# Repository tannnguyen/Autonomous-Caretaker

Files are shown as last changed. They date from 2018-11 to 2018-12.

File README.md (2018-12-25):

# Autonomous Caretaker

Autonomous Caretaker is the final project for class 530.420 Mechatronics in Spring 2017 at Johns Hopkins University. As a team of engineers, we built a futuristic robot that can recognize and put off fire and then rescue another robot on its way back to base. We want to share our results (including Arduino codes, 3D design, and circuit).

## Mission
Given a hypothetical situation in the future where everyone has a supporting robot with them. An elderly human is sleeping on the beach and forgets to put off the campfire. The robot needs to recognize the fire, alert the elders to wake up, collect the water, put off the fire, and then bring some water back to the elderly. 

## Approach
For our robot, we plan to build a 2-story robot where it can store water in a syringe system at the bottom and all the control system is on top. We use 2 Arduinos, each controls a story within the robot. To support this robot, we use a 4-wheel robot for stability, Pixy for color and object recognition, various types of motors to control different moving components in the robot.

Our steps to solve the problems:

    Milestone 1: 
    Step 1: Looking for the fire (registered by the color red)
    Step 2: Once found, looking for the elderly
    Step 3: Move towards the elderly
    Step 4: Once reach the elderly, turn on the siren
    Step 4.5 (for elderly): Elderly hears the siren and move to safety

    Milestone 2:
    Step 5: Move backward and look for the water (registered by the color blue)
    Step 6: Identify where the water is
    Step 7: Move to the water.
    Step 8: Pick up the water (send signal to bottom Arduino)
    Step 9: Move back a bit, look for the fire
    Step 10: Go to the fire.
    Step 11: Distribute the water (send the signal to the bottom Arduino)
    Step 12: Go to the elderly.
    Step 13: Distribute the water to the elderly.
  
## Code, Design, and Circuit
Please refer to Code/ and Parts/ folders to see and download our codes and design. Refer to [Parts.md](https://github.com/tannnguyen/Autonomous-Caretaker/blob/master/Parts.md) for our parts

This is our mechanical design:
<p>
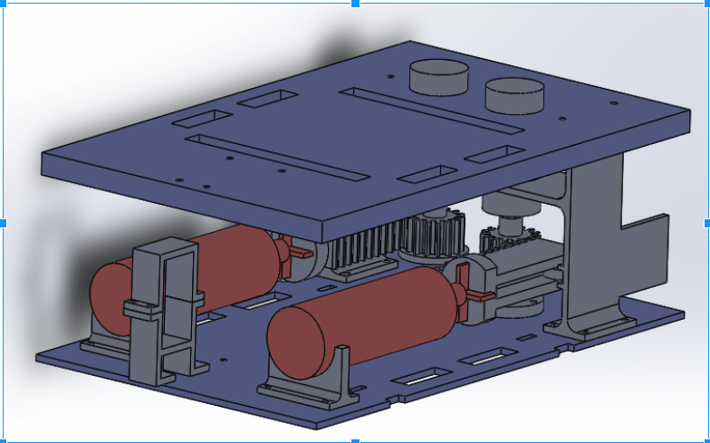
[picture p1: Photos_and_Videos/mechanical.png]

</p>

This is our circuit:
<p>
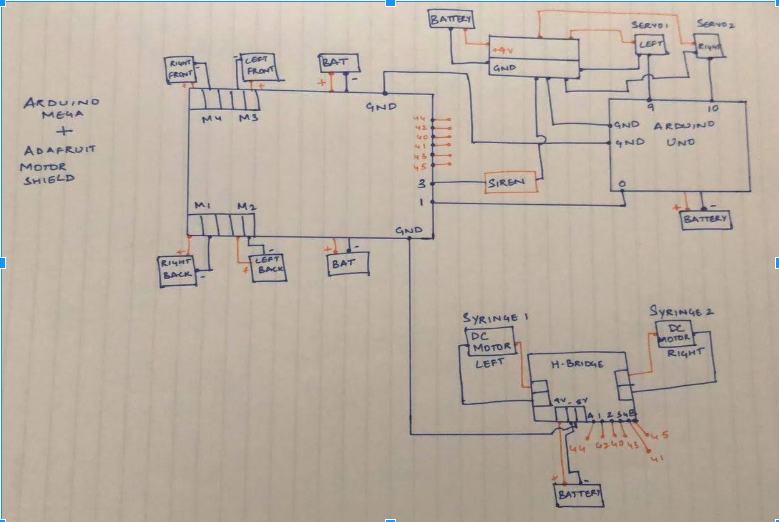
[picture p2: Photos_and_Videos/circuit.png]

</p>
This is our final robot:
<p>


 
</p>

## Demo
* Challenge 1: Please refer to this [video1](https://github.com/tannnguyen/Autonomous-Caretaker/blob/master/Photos_and_Videos/challenge1_robot.mp4) [video2](https://github.com/tannnguyen/Autonomous-Caretaker/blob/master/Photos_and_Videos/elderly.mp4)
* Challenge 2:Please refer to this [video](https://github.com/tannnguyen/Autonomous-Caretaker/blob/master/Photos_and_Videos/challenge2.mp4)
* We did not have a chance to take video of our final demo with complete steps...

## Technology
* Ardunio and its libraries
* SolidWorks (for 3D printed and lasercut part)
* Mechanical and electrical components needed to build the robot

## Authors
* Tan Nguyen
* Darshini Balamurugan
* Mona Gao

## Acknowledgement
* A lot of help and support from Morris Kraicer, Ethan Tang, Joseph Pan, and Paola Donis
* A lot of guidance from Professor Charbel Rizk

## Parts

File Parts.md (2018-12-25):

# Material List

This is all the parts we used for both the main robot and the elderly

* 1x Arduino Mega and 2x Arduino Uno
* 1x Siren
* 2x 9V DC Motors with Encoders
* 2x Positional servo motors
* 2x Chassis (Acrylic laser cut)
* 1x Pixy
* 1x Ping sensor
* Multiple 3D printed parts for support and connectors
* 8x gearbox motors and wheels (for both elderly and caretaker)
* 1x Sound Detector
* 2x Adafruit Motor shield
* 1x H-bridge
* 2x Syringes and tubes
* 1x Colored paper
* Multiple breadboards

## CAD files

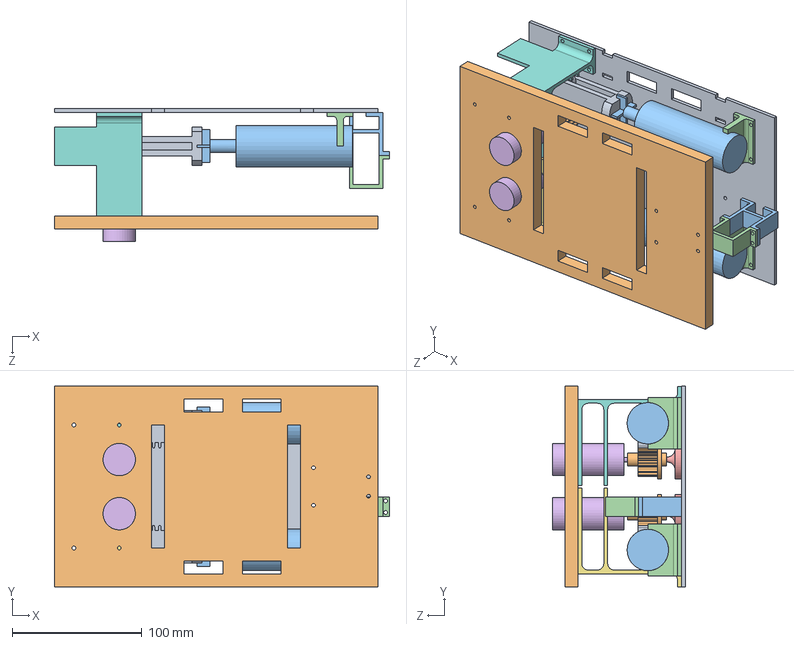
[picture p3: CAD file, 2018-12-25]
Design/syringe_system_two.SLDASM
258.7 x 155.0 x 102.5 mm
Part3rack x 2
Part1pinion125 x 2
syringe_model x 2
syringe_holder x 2
gear_stand x 2
motor_model x 2
motor_roller_wheel_holder_wall
holder_wall_mirror
chassis_4_25 (1)
top_chassis_04_26
servo_motor_support_04_27
servo_motor_upper_support

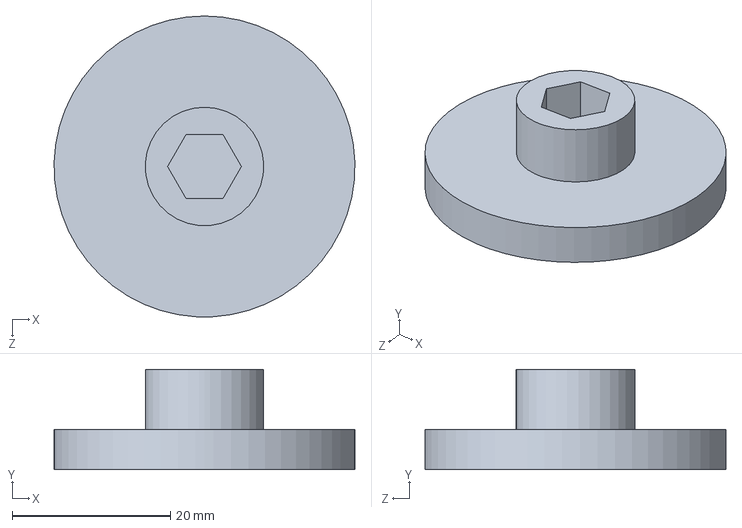
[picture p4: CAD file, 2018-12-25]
Design/syringe_end_holder.SLDPRT
38.1 x 12.7 x 38.1 mm

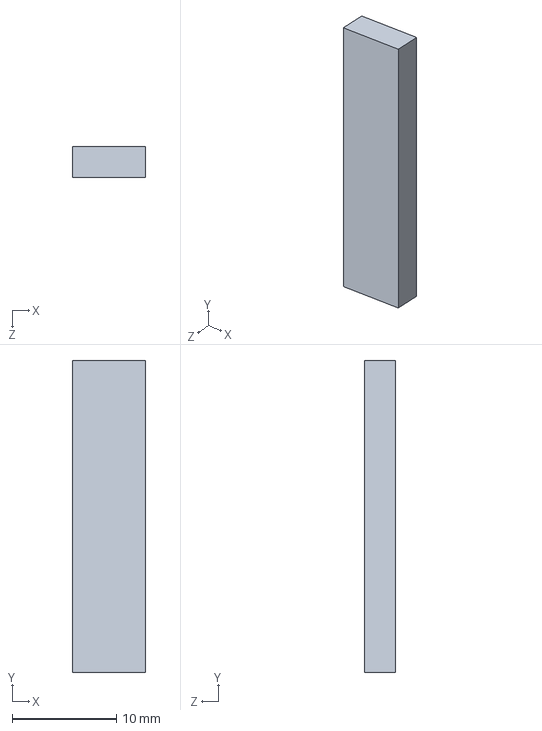
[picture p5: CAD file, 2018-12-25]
Design/slider_piece_end_stopper.SLDPRT
7.00 x 30.0 x 3.00 mm

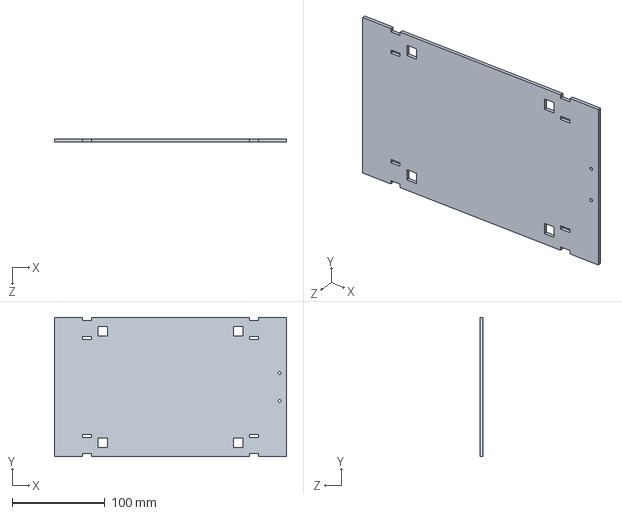
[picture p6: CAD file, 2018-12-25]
Design/robot.SLDPRT
250.0 x 150.0 x 3.00 mm

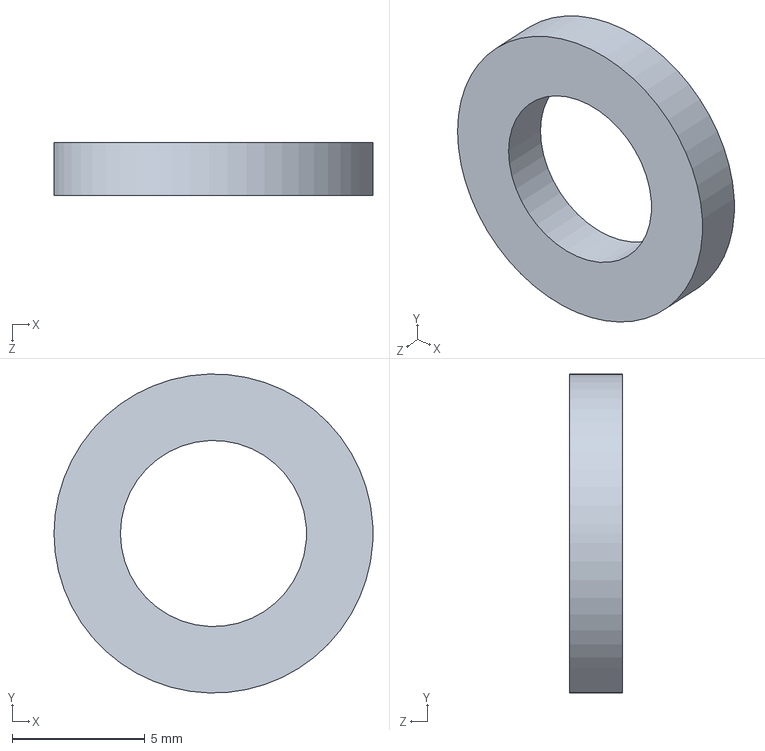
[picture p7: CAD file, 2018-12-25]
Design/bearing_holder_horizontal.SLDPRT
12.0 x 12.0 x 2.00 mm

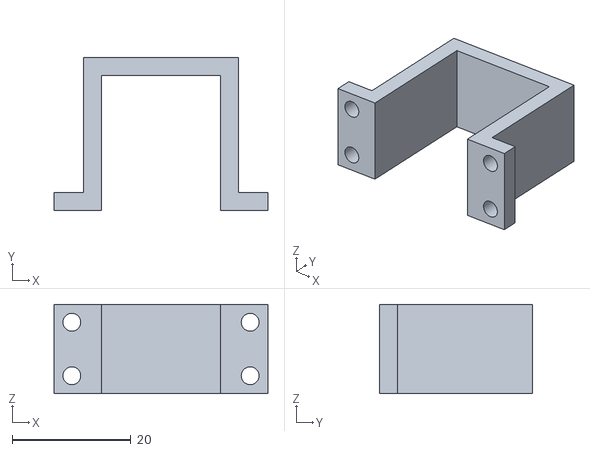
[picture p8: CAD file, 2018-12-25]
Design/servo_motor_upper_support_04_28.STL
36.0 x 25.7 x 15.0

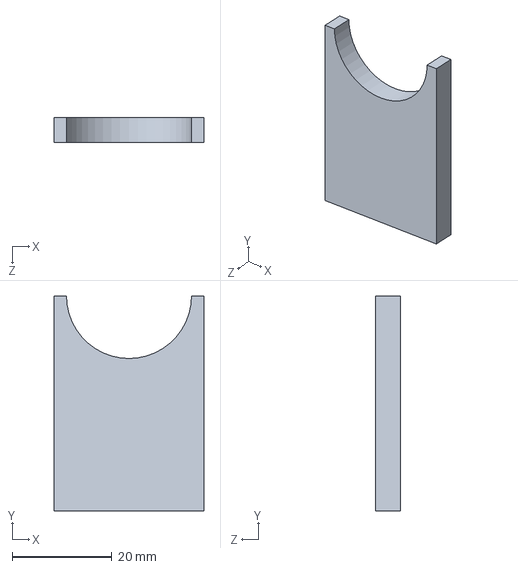
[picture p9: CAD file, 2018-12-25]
Design/motor_positioner.SLDPRT
30.0 x 43.0 x 5.00 mm

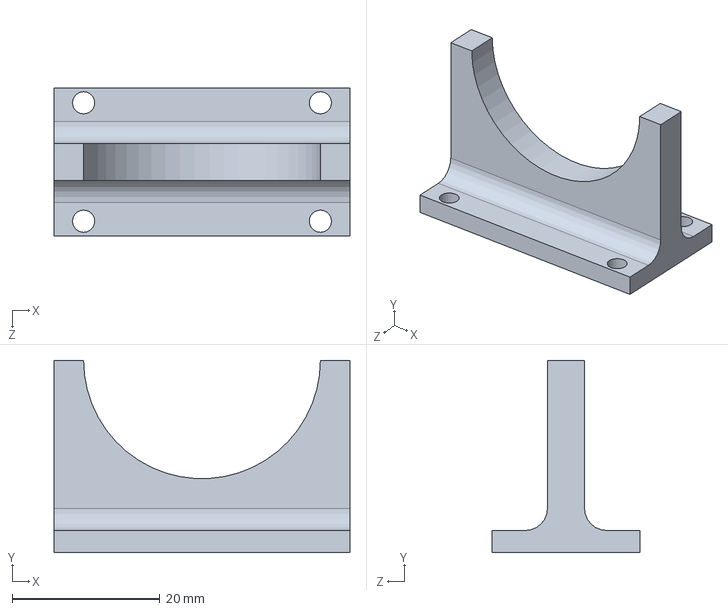
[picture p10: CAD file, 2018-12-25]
Design/syringe_holder.SLDPRT
40.0 x 26.0 x 20.0 mm

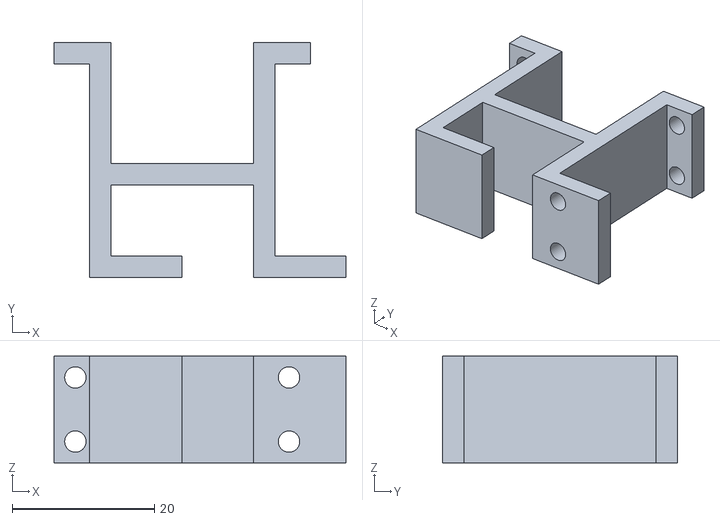
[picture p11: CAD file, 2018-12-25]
Design/servo_motor_support_04_28.STL
41.0 x 33.0 x 15.0

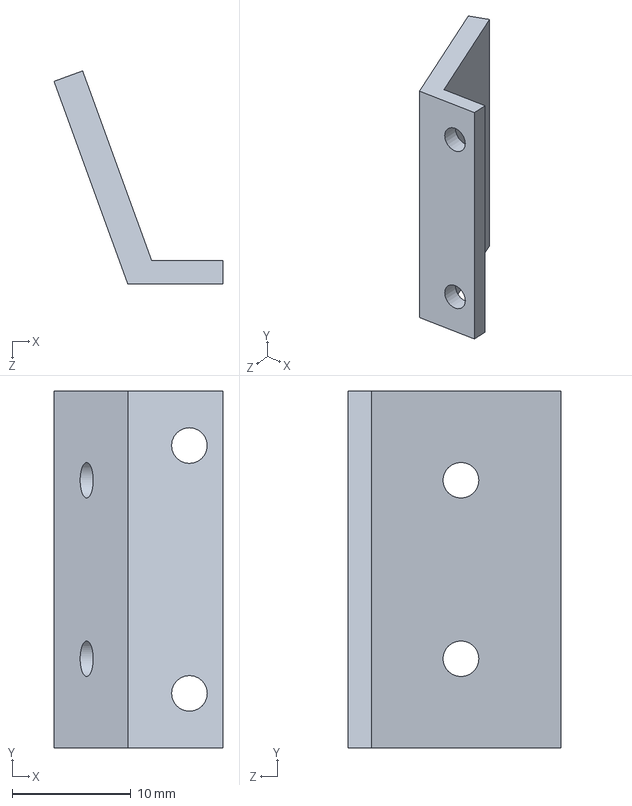
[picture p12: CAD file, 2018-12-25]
Design/pixy_slanted.SLDPRT
14.2 x 30.0 x 17.9 mm

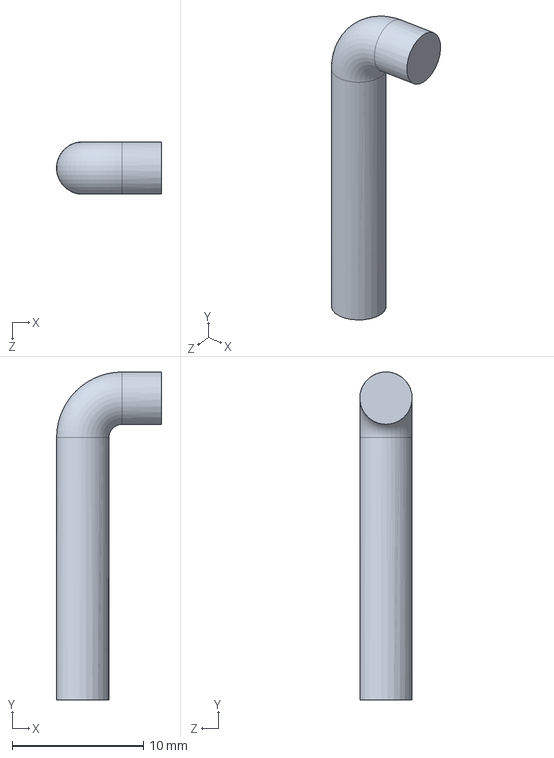
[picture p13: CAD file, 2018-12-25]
Design/arm_between_gear_roller.SLDPRT
8.00 x 25.0 x 4.00 mm

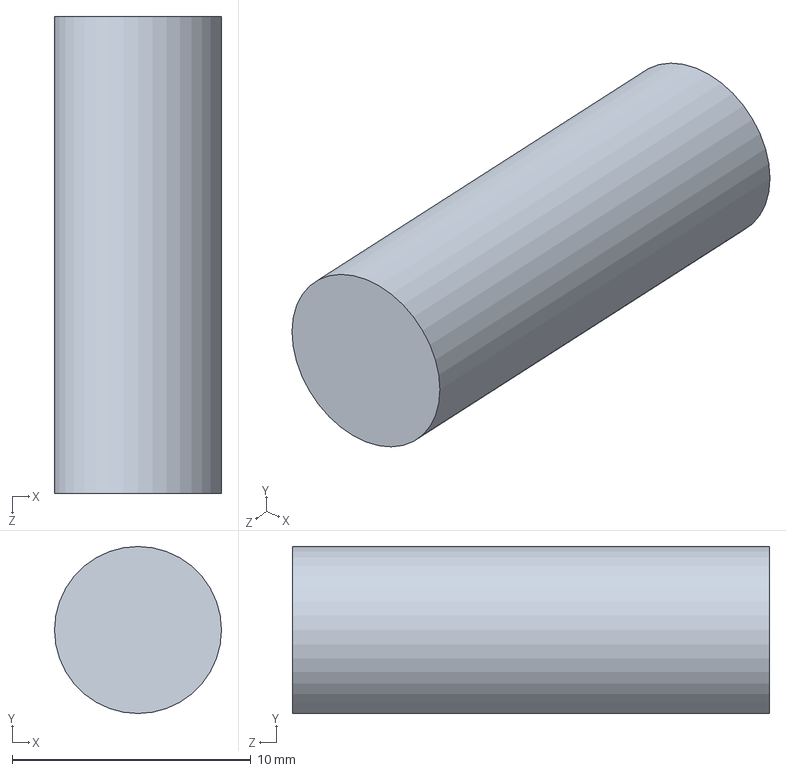
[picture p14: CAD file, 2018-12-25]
Design/shaft_to_gear.SLDPRT
7.00 x 7.00 x 20.0 mm

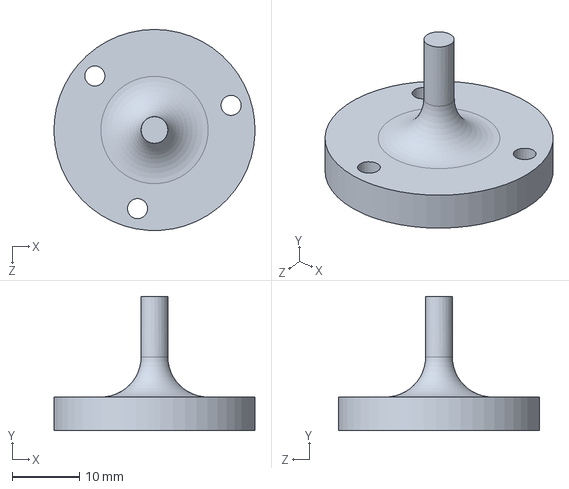
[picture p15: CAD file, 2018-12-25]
Design/gear_stand.SLDPRT
30.0 x 20.0 x 30.0 mm

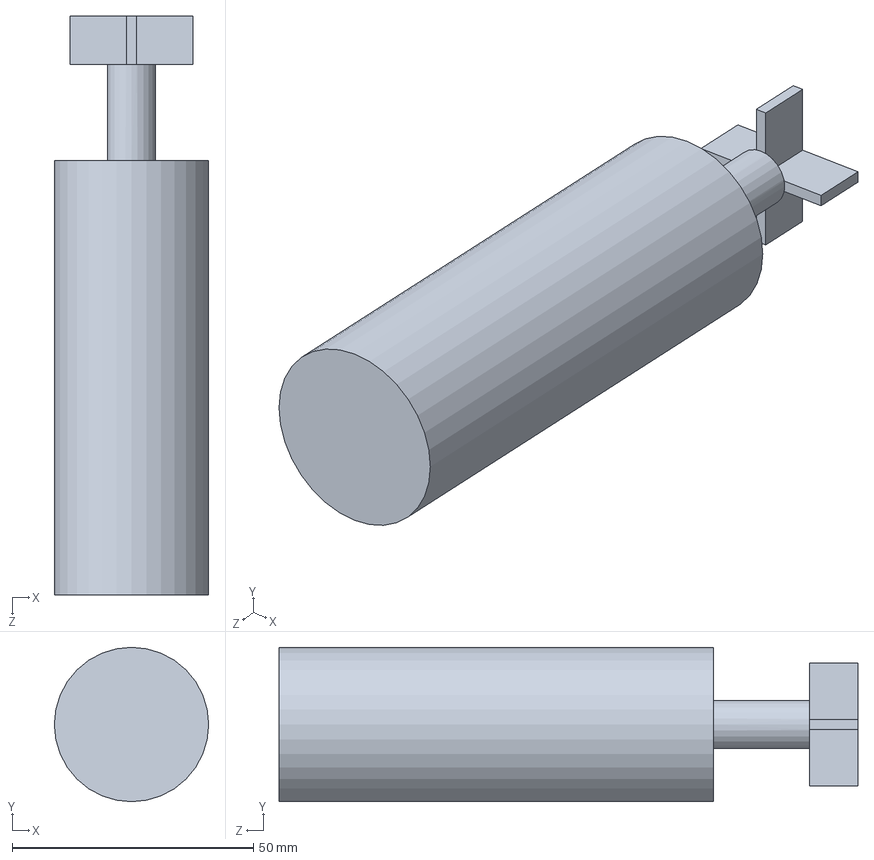
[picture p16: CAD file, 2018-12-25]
Design/syringe_model.SLDPRT
32.0 x 32.0 x 120.0 mm

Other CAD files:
Design/T for wheels2.SLDPRT
Design/syringe_holder_mirror.STL
Design/part3rack_mirror.STL
Design/holder_wall_mirror.STL
Design/Part1pinion125_04_28.STL
Design/elderly_laser_cut_04_06_18.SLDPRT
Design/motor_model.SLDPRT
Design/motor_roller_wheel_holder_wall.SLDPRT
Design/top_chassis_04_26.SLDPRT

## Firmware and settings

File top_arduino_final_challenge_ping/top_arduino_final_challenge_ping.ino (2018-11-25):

#include <Wire.h>
#include <Adafruit_MotorShield.h>
#include "utility/Adafruit_MS_PWMServoDriver.h"

// Include headers for SPI port and pixy camera
#include <SPI.h>
#include <Pixy.h>

// Define all speeds and delay here
#define water 3000
#define hose 500
#define rotateSpeed 200

// Define all ports here
#define siren 3
#define signalPin 2
#define ping 7
#define enA 45
#define enB 44
#define in1 43
#define in2 41
#define in3 42
#define in4 40
/*
   Decode for motors:
   Left syringe is 45 43 41 with 41 HIGH means Pull
   Right syringe is 44 42 40 with 42 HIGH means Pull
*/

// Create the motor shield object with the default I2C address
Adafruit_MotorShield AFMS = Adafruit_MotorShield();

// Select which 'port' M1, M2, M3 or M4. In this case, M1
Adafruit_DCMotor *leftFrontMotor = AFMS.getMotor(3);
// You can also make another motor on port M2
Adafruit_DCMotor *rightFrontMotor = AFMS.getMotor(2);
Adafruit_DCMotor *rightBackMotor = AFMS.getMotor(1);
Adafruit_DCMotor *leftBackMotor = AFMS.getMotor(4);

Pixy pixy;

//put all the variables here!
int color_fire = -1;
int color_elderly = -1;
int color_water = -1;

uint16_t blocks;
int x = -1;
int area = -1;
int height = -1;
// stores horizontal distance of object in Pixy camera

void setup() {
  // put your setup code here, to run once:
  AFMS.begin(); // create with default frequency 1.6KHz or pass hz value in function
  pixy.init();
  Serial.begin(9600);
  pinMode(siren, OUTPUT);
  pinMode(enA, OUTPUT);
  pinMode(enB, OUTPUT);
  pinMode(in1, OUTPUT);
  pinMode(in2, OUTPUT);
  pinMode(in3, OUTPUT);
  pinMode(in4, OUTPUT);
  pinMode(signalPin, OUTPUT);
  digitalWrite(signalPin, LOW);
  // Set the constant speed of the syringe
  analogWrite(enA, 225);
  analogWrite(enB, 235);
  delay(5000);
}

void loop() {
  /*
     Challenge 1 code right here
     Step 1: Looking for the fire (red)
     Step 2: Once found, looking for the elderly
     Step 3: Move towards the elderly. Trying to center it
     Step 4: Turn on the siren
     Step 5: Move backward and look for the water
  */

  // Step 1: Looking for red

  color_fire = -1;
  while (color_fire == -1) {
    rotateLeft(rotateSpeed);
    Serial.println("Looking for fire");
    blocks = pixy.getBlocks();
    // The blocks need to be red. Signature 1.
    if (blocks) {
      for (int j = 0; j < blocks; j++) {
        if (pixy.blocks[j].signature == 1) {
          color_fire = j;
        }
      }
    }
  }
  Serial.println("I found red here");
  // Step 1.5: Checking for the ping to make sure that we are allowed to go
  long distance = measureDistance();
  // Check if we will get stuck as we find the elderly or not
  if (distance < 70) {
    //Looking for the water to center itself first
    color_water = -1;
    while (color_water == -1) {
      rotateLeft(rotateSpeed);
      Serial.println("Looking for the water");
      blocks = pixy.getBlocks();
      if (blocks) {
        for (int j = 0; j < blocks; j++) {
          if (pixy.blocks[j].signature == 2) {
            color_water = j;
            area = pixy.blocks[j].height * pixy.blocks[j].width;
            x = pixy.blocks[j].x;
          }
        }
      }
    }
    // Trying to center the robot with the water
    while (x < 160) {
      rotateRight(130);
      blocks = pixy.getBlocks();
      if (blocks) {
        for (int j = 0; j < blocks; j++) {
          // If there is noise in the environment, check for the largest object
          if (pixy.blocks[j].signature == 2) {
            x = pixy.blocks[j].x;
          }
        }
      }
    }
    while (distance < 70) {
      forward(200);
      distance = measureDistance();
    }
  }
  // Step 2: Found red here, looking for the elderly next
  int x = -1;
  int height = 0;
  //find the elderly and turn to it
  color_elderly = -1;
  while (color_elderly == -1) {
    // Need to pan to search for the robot
    rotateRight(rotateSpeed);
    Serial.println("Looking for the elderly");
    // Use Pixy to search for the robot
    blocks = pixy.getBlocks();
    // The blocks need to be green. Signature 3.
    if (blocks) {
      for (int j = 0; j < blocks; j++) {
        if (pixy.blocks[j].signature == 3) {
          color_elderly = j;
          height = pixy.blocks[j].height;
          x = pixy.blocks[j].x;
        }
      }
    }
  }

  // Stop the robot and ready to center with the elderly.
  forward(0);
  delay(50);
  Serial.println("I found the elderly");
  // Step 3: Move towards the elderly (at a 12in distance)
  while (height < 80) {
    if (x < 160) {
      //elderly on the left of rescue robot
      turnForward(100, 190);
    } else {
      //elderly on the right of rescue robot
      turnForward(190, 100);
    }
    blocks = pixy.getBlocks();
    if (blocks) {
      color_elderly = -1;
      for (int j = 0; j < blocks; j++) {
        Serial.println("Moving towards the elderly right now");
        // If there is noise in the environment, check for the largest object
        if (pixy.blocks[j].signature == 3) {
          color_elderly = j;
          height = pixy.blocks[j].height;
          x = pixy.blocks[j].x;
        }
      }
    }
  }

  //Stop the robot
  forward(0);
  delay(50);
  Serial.println("I found the elderly");
  // Step 4: Turn on the siren
  digitalWrite(siren, HIGH);
  delay(3000);
  digitalWrite(siren, LOW);
  // Step 5: Move backward
  backward(200);
  delay(500);


  //       Challenge 2:
  //        Step 1: Identify where the water is
  //        Step 2: Move to the water.
  //        Step 3: Pick up the water. (Send the signal to the other Arduino)
  //        Step 4: Move back a bit, look for the fire
  //        Step 5: Go to the fire.
  //        Step 6: Distribute the water (send the signal to the Arduino)
  //        Step 7: Go to the elderly.
  //        Step 8: Distribute the water to the elderly.

  // Step 1: Identify where the water is
  area = -1;
  x = -1;
  color_water = -1;
  rotateLeft(rotateSpeed);
  delay(1000);
  while (color_water == -1) {
    rotateLeft(rotateSpeed);
    Serial.println("Looking for the water");
    blocks = pixy.getBlocks();
    if (blocks) {
      for (int j = 0; j < blocks; j++) {
        if (pixy.blocks[j].signature == 2) {
          color_water = j;
          area = pixy.blocks[j].height * pixy.blocks[j].width;
          x = pixy.blocks[j].x;
        }
      }
    }
  }
  Serial.println("I found the water here");
  // Found the water here.
  // Step 2: Move towards the water
  // Stop at certain area. Need to change this threshold here!
  while (area < 10000) {
    if (x < 160) {
      //water on the left of the robot
      turnForward(100, 190);
    } else {
      //water on the right of rescue robot
      turnForward(190, 100);
    }
    Serial.println("Moving towards the water");
    blocks = pixy.getBlocks();
    if (blocks) {
      for (int j = 0; j < blocks; j++) {
        // If there is noise in the environment, check for the largest object
        if (pixy.blocks[j].signature == 2) {
          area = pixy.blocks[j].width * pixy.blocks[j].height;
          x = pixy.blocks[j].x;
        }
      }
    }
  }
  // Should stop at the water area here.
  // Move to the edge of the water.
  forward(0);
  delay(50);
  Serial.println("Moving slowly to the water");
  turnForward(200, 170);
  delay(1000);
  forward(0);

  // Step 3: Pick up the water
  pullWater();

  // Step 4: Move back and look for fire
  backward(200);
  delay(800);
  // Look around for the fire
  height = 0;
  color_fire = -1;
  while (color_fire == -1) {
    Serial.println("I am looking for the fire");
    // Need to pan to search for the robot
    rotateRight(rotateSpeed);
    // Use Pixy to search for the robot
    blocks = pixy.getBlocks();
    // The blocks need to be red. Signature 1.
    if (blocks) {
      for (int j = 0; j < blocks; j++) {
        // If there is noise in the environment, check for the largest object
        if (pixy.blocks[j].signature == 1) {
          color_fire = j;
          height = pixy.blocks[j].height;
          x = pixy.blocks[j].x;
        }
      }
    }
  }
  // Found the fire here
  // Step 5: Go to the fire
  while (height < 110) {
    if (x < 140) {
      //elderly on the left of rescue robot
      turnForward(100, 150);
    } else if (x >= 140 && x < 180) {
      turnForward(120, 120);
    } else {
      //elderly on the right of rescue robot
      turnForward(150, 100);
    }
    Serial.println("Moving towards the fire");
    blocks = pixy.getBlocks();
    if (blocks) {
      for (int j = 0; j < blocks; j++) {
        // If there is noise in the environment, check for the largest object
        if (pixy.blocks[j].signature == 1) {
          height = pixy.blocks[j].height;
          x = pixy.blocks[j].x;
        }
      }
    }
  }
  // In the fire area. Go to the fire.

  forward(0);
  delay(100);
  forward(200);
  delay(200);
  forward(0);
  Serial.println("Moving slowly towards the fire");
  while (x > 100) {
    rotateLeft(130);
    blocks = pixy.getBlocks();
    if (blocks) {
      for (int j = 0; j < blocks; j++) {
        // If there is noise in the environment, check for the largest object
        if (pixy.blocks[j].signature == 1) {
          x = pixy.blocks[j].x;
        }
      }
    }

  }
  // Step 6: Distribute the water to the fire
  forward(0);
  pushLeft();


  // Step 7: Look for the elderly
  backward(100);
  delay(500);
  forward(0);
  height = 0;
  color_elderly = -1;
  while (color_elderly == -1) {
    // Need to pan to search for the robot
    rotateRight(rotateSpeed);
    Serial.println("Looking for the elderly");
    // Use Pixy to search for the robot
    blocks = pixy.getBlocks();
    // The blocks need to be green. Signature 3.
    if (blocks) {
      Serial.println("I can find blocks");
      for (int j = 0; j < blocks; j++) {
        // If there is noise in the environment, check for the largest object
        if (pixy.blocks[j].signature == 3) {
          color_elderly = j;
          height = pixy.blocks[j].height;
          x = pixy.blocks[j].x;
        }
      }
    }
  }

  // Step 8: Go to the elderly
  forward(0);
  delay(50);
  while (height < 80) {
    if (x < 150) {
      //elderly on the left of rescue robot
      turnForward(100, 150);
    } else if (x >= 150 && x < 170) {
      turnForward(120, 120);
    } else {
      //elderly on the right of rescue robot
      turnForward(150, 100);
    }
    Serial.println("I am running towards the elderly");
    blocks = pixy.getBlocks();
    if (blocks) {
      for (int j = 0; j < blocks; j++) {
        // If there is noise in the environment, check for the largest object
        if (pixy.blocks[j].signature == 3) {
          color_elderly = j;
          height = pixy.blocks[j].height;
          x = pixy.blocks[j].x;
        }
      }
    }
  }
  // Got to the elderly
  // Step 9: Distribute the water to the elderly
  forward(0);
  delay(50);
  Serial.println("Going slowly towards the elderly");
  forward(100);
  delay(300);
  while (x < 150) {
    rotateRight(130);
    blocks = pixy.getBlocks();
    if (blocks) {
      for (int j = 0; j < blocks; j++) {
        // If there is noise in the environment, check for the largest object
        if (pixy.blocks[j].signature == 1) {
          x = pixy.blocks[j].x;
        }
      }
    }
  }

  forward(0);
  pushRight();
  backward(200);
  delay(100);

  // Stop everything
  forward(0);
  delay(100000000);
}

void forward(int i) {
  leftFrontMotor->setSpeed(i);
  leftFrontMotor->run(FORWARD);
  leftBackMotor->setSpeed(i);
  leftBackMotor->run(FORWARD);
  rightBackMotor->setSpeed(i);
  rightBackMotor->run(FORWARD);
  rightFrontMotor->setSpeed(i);
  rightFrontMotor->run(FORWARD);
}


void backward(int i) {
  leftFrontMotor->setSpeed(i);
  leftFrontMotor->run(BACKWARD);
  leftBackMotor->setSpeed(i);
  leftBackMotor->run(BACKWARD);
  rightBackMotor->setSpeed(i);
  rightBackMotor->run(BACKWARD);
  rightFrontMotor->setSpeed(i);
  rightFrontMotor->run(BACKWARD);
}

// when lm > rm, right turn
// when rm > lm, left turn
void turnForward(int lm, int rm) {
  leftFrontMotor->setSpeed(lm);
  leftFrontMotor->run(FORWARD);
  leftBackMotor->setSpeed(lm);
  leftBackMotor->run(FORWARD);
  rightBackMotor->setSpeed(rm);
  rightBackMotor->run(FORWARD);
  rightFrontMotor->setSpeed(rm);
  rightFrontMotor->run(FORWARD);
}

void turnBackward(int lm, int rm) {
  leftFrontMotor->setSpeed(lm);
  leftFrontMotor->run(BACKWARD);
  leftBackMotor->setSpeed(lm);
  leftBackMotor->run(BACKWARD);
  rightBackMotor->setSpeed(rm);
  rightBackMotor->run(BACKWARD);
  rightFrontMotor->setSpeed(rm);
  rightFrontMotor->run(BACKWARD);

}

void rotateLeft(int i) {
  leftFrontMotor->setSpeed(i);
  leftFrontMotor->run(FORWARD);
  leftBackMotor->setSpeed(i);
  leftBackMotor->run(FORWARD);
  rightBackMotor->setSpeed(i);
  rightBackMotor->run(BACKWARD);
  rightFrontMotor->setSpeed(i);
  rightFrontMotor->run(BACKWARD);

}

void rotateRight(int i) {
  leftFrontMotor->setSpeed(i);
  leftFrontMotor->run(BACKWARD);
  leftBackMotor->setSpeed(i);
  leftBackMotor->run(BACKWARD);
  rightBackMotor->setSpeed(i);
  rightBackMotor->run(FORWARD);
  rightFrontMotor->setSpeed(i);
  rightFrontMotor->run(FORWARD);
}

void pullWater() {
  // Servo so the hose goes down
  digitalWrite(signalPin, HIGH);
  delay(hose);
  // Pull water in. Adjust the delay for the amount
  digitalWrite(in4, LOW);
  digitalWrite(in3, HIGH);
  digitalWrite(in2, HIGH);
  digitalWrite(in1, LOW);
  delay(water);

  // Stop pulling water now
  digitalWrite(in4, LOW);
  digitalWrite(in3, LOW);
  digitalWrite(in2, LOW);
  digitalWrite(in1, LOW);
  //Put it to the top
  digitalWrite(signalPin, LOW);
}

void pushLeft() {
  // Push the left motor out
  analogWrite(enB, 200);
  analogWrite(enA, 200);
  digitalWrite(in1, HIGH);
  delay(water * 1.5);

  // Stop pushing now
  digitalWrite(in1, LOW);
  // Put servo up
}

void pushRight() {
  // Push the right motor out
  digitalWrite(in4, HIGH);
  delay(water);

  // Stop pushing now
  digitalWrite(in4, LOW);
}

//For each ultrasound sensor pin to send the signal
long measureDistance() {
  long duration, cm;

  pinMode(ping, OUTPUT);

  digitalWrite(ping, LOW);
  delayMicroseconds(5);
  digitalWrite(ping, HIGH);
  delayMicroseconds(5);
  digitalWrite(ping, LOW);

  pinMode(ping, INPUT);
  duration = pulseIn(pin, HIGH);

  cm = microseconds / 29 / 2;
  return cm;
}

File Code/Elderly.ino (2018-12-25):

/**
 * Code for the elderly robot
 * 
 * Use a sound sensor to know when to start the elderly. If the elderly hears
 * the siren for a certain period of time (use this to avoid noises), it will
 * start and run to safety based on a predefined path. 
 * 
 * Use Adafruit MotorShield to control the movement as well
 * 
 **/

#include <Wire.h>
#include <Adafruit_MotorShield.h>
#include "utility/Adafruit_MS_PWMServoDriver.h"
#define sensor A1

// Fix this to control the right wheels
Adafruit_MotorShield AFMS = Adafruit_MotorShield();
Adafruit_DCMotor *leftFrontMotor = AFMS.getMotor(2);
Adafruit_DCMotor *rightFrontMotor = AFMS.getMotor(1);
Adafruit_DCMotor *leftBackMotor = AFMS.getMotor(3);
Adafruit_DCMotor *rightBackMotor = AFMS.getMotor(4);

void setup() {
  AFMS.begin();
  pinMode(sensor, INPUT);
}

void loop() {
  int sensorval1 = analogRead(sensor);
  
  // If the sound is loud enough, it is not noise and the elderly can move
  // towards safety.
  if (sensorval1 > 100) {
    // Run a pre-defined path
    delay(2000);
    forward(200);
    delay(1250);
    turnForward(200, 0);
    delay(900);
    forward(200);
    delay(850);
    forward(0);
    delay(30000);
  }
}

// Move straight forward
void forward(int i) {
  leftFrontMotor->setSpeed(i);
  leftFrontMotor->run(FORWARD);

  rightFrontMotor->setSpeed(i);
  rightFrontMotor->run(FORWARD);

  leftBackMotor->setSpeed(i);
  leftBackMotor->run(FORWARD);

  rightBackMotor->setSpeed(i);
  rightBackMotor->run(FORWARD);

}

// Move straight backward
void backward(int i) {
  leftFrontMotor->setSpeed(i);
  leftFrontMotor->run(BACKWARD);

  rightFrontMotor->setSpeed(i);
  rightFrontMotor->run(BACKWARD);

  leftBackMotor->setSpeed(i);
  leftBackMotor->run(BACKWARD);

  rightBackMotor->setSpeed(i);
  rightBackMotor->run(BACKWARD);
}

// Turn left or right forward
void turnForward(int lm, int rm) {
  leftFrontMotor->setSpeed(lm);
  leftFrontMotor->run(FORWARD);

  rightFrontMotor->setSpeed(rm);
  rightFrontMotor->run(FORWARD);
  
  leftBackMotor->setSpeed(lm);
  leftBackMotor->run(FORWARD);

  rightBackMotor->setSpeed(rm);
  rightBackMotor->run(FORWARD);
}

// Turn left or right backward
void turnBackward(int lm, int rm) {
  leftFrontMotor->setSpeed(lm);
  leftFrontMotor->run(BACKWARD);

  rightFrontMotor->setSpeed(rm);
  rightFrontMotor->run(BACKWARD);

  leftBackMotor->setSpeed(lm);
  leftBackMotor->run(BACKWARD);

  rightBackMotor->setSpeed(rm);
  rightBackMotor->run(BACKWARD);

}

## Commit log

2018-11-25 Upload Arduino code
2018-12-25 Add some 3D printed designs
    [Part1pinion125_04_28.STL, T for wheels2.SLDPRT, arm_between_gear_roller.SLDPRT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]
